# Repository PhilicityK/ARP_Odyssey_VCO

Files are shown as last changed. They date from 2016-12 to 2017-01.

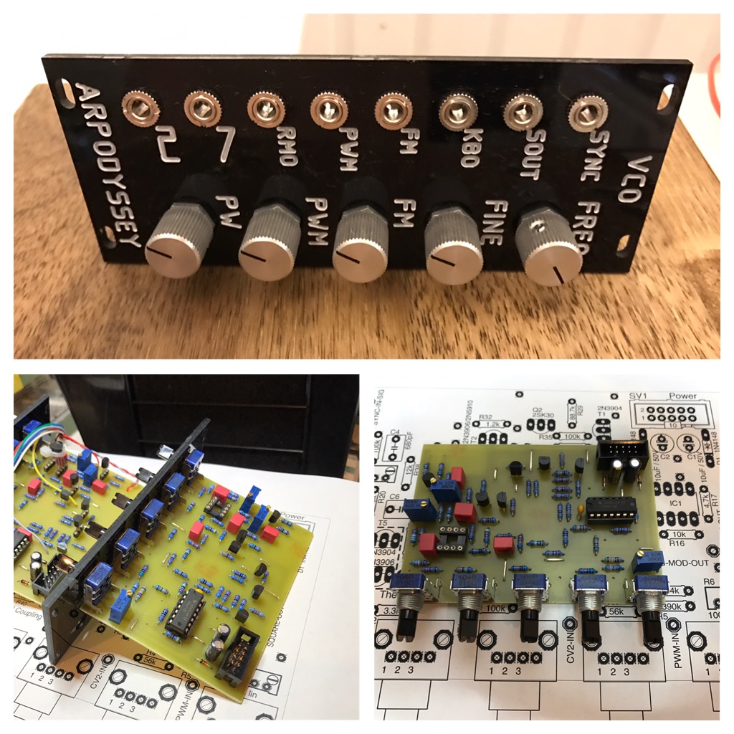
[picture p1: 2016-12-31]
images/IMG_5406.JPG

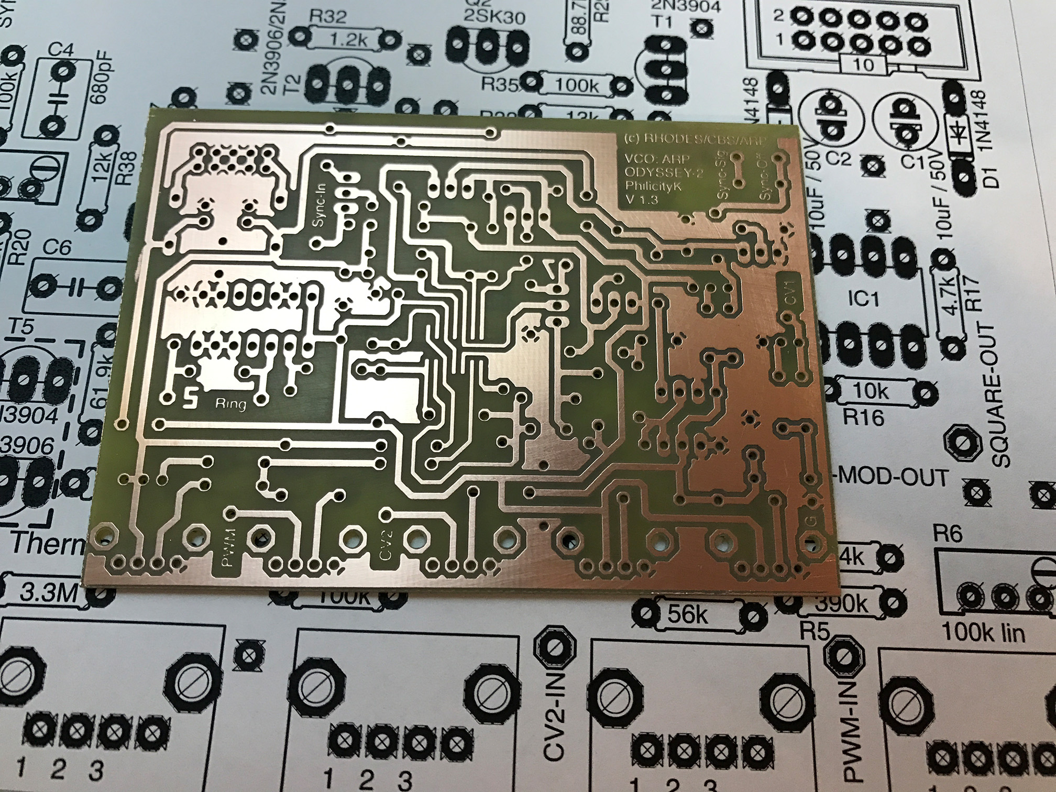
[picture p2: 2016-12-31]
images/finished-pcb.jpg

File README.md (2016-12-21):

ARP_Odyssey_VCO

Modular Version of the ARP ODYSSEY MKII/III VCO

ABOUT THIS PROJECT

Dreaming of my own modular synthesizer for many years, I've decided to finally start a DIY project. First of all I wanted to build a module which allows me to create sounds. I mean what’s the most exited thing about synthesizers? Right! Turning knobs, altering sounds and waveforms! ;) Therefore I have chosen to build the VCO from an ARP ODYSSEY MKII. If you are not familiar with the ODYSSEY just head over to Youtube and have a quick listen to it. It sounds awesome! :)

ABOUT THE CIRCUIT

The great thing about vintage electronics is the availability of official service and repair manuals. I’ve found one for the ARP ODYSSEY online:
http://www.arpodyssey.com/manuals/Arp%20Odyssey%20Service%20Manual.pdf

With the original schematics at my fingertips it was fairly easy to find the VCO section. I’ve used the latest version of EAGLE (7.7.0) to rebuild the circuit. My goal was to keep it simple by using parts which are still available and easily obtainable. I was able to get everything at my distributor of choice (www.reichelt.de). The VCO operates at +/-15V. It might be possible to use it with +/-12V to create sounds, but at lower voltages the CV-tracking will be most likely inaccurate.
This thread over at electro-music gave me a few ideas on how to design my front panel: 
http://files.electro-music.com/forum/topic-54502.html

BUILDING PROCESS

The PCB is home etched and drilled on my DIY CNC machine. 
Soldering is done with an ERSA soldering iron.
The front panel is created from black acrylic which is CNC machined as well.
I’ve used a white pen with a fine tip to fill in the engraved font.

Have a look at the wiki for further informations on building this module.

IMPORTANT

I have not created the schematics for the ARP Odyssey MKII/III VCO. I have just reworked the layout for all the DIY synth builders out there.

Copyright exists (Rhodes/CBS/ARP). No infringement is intended. The files are for experimental and educational purposes only. All the credits for the schematics go to the copyright holder.

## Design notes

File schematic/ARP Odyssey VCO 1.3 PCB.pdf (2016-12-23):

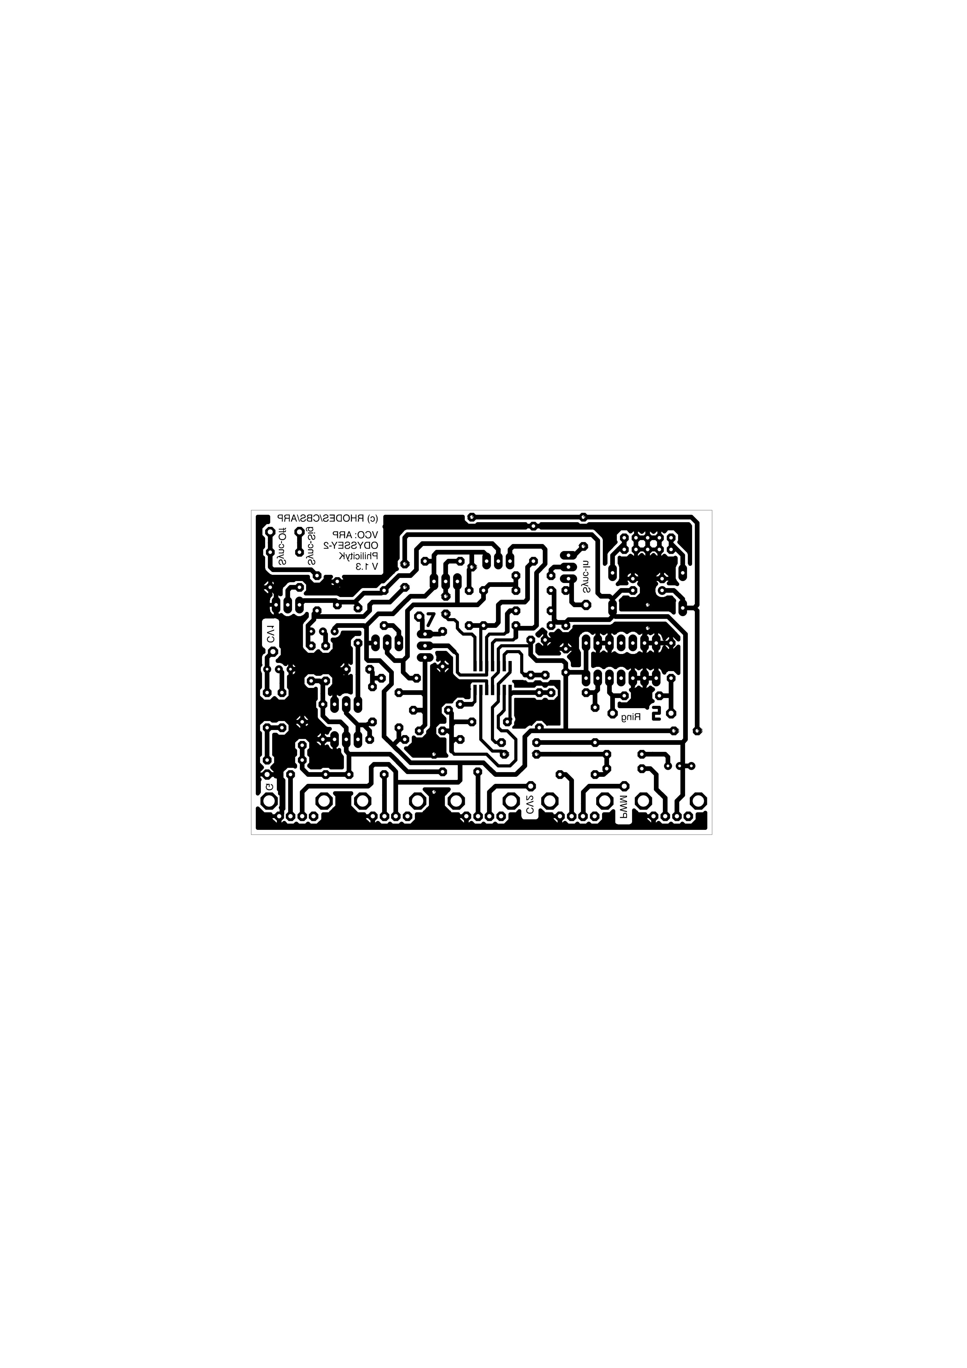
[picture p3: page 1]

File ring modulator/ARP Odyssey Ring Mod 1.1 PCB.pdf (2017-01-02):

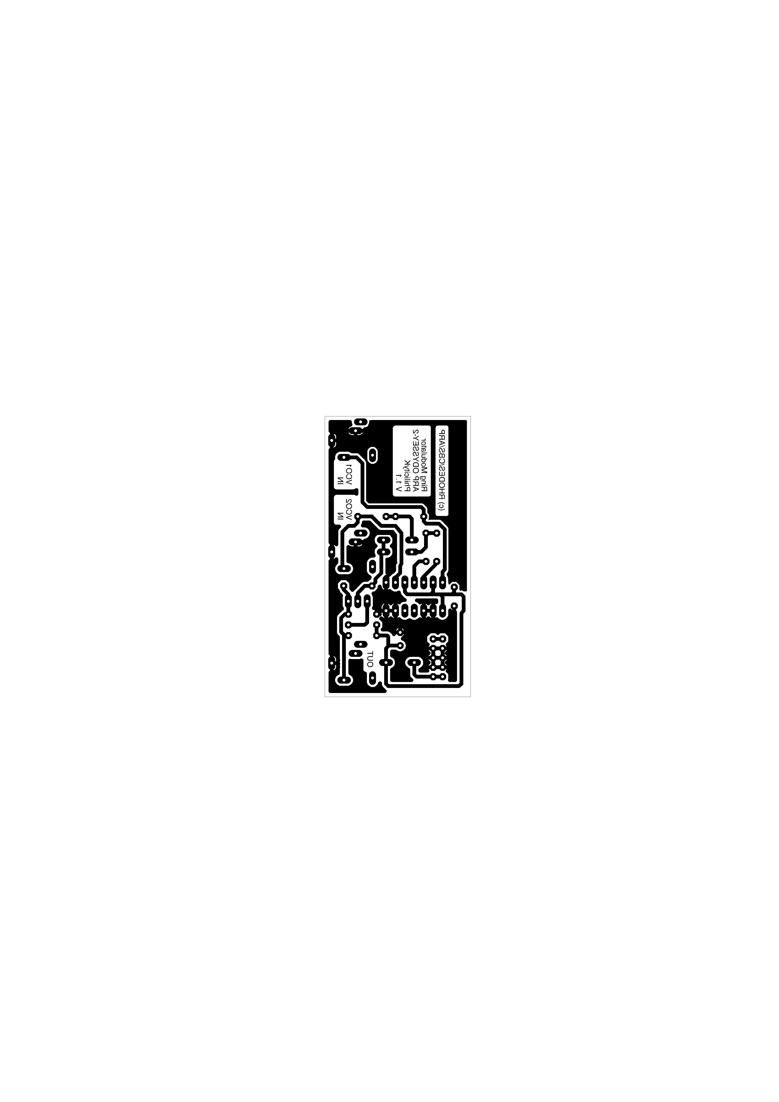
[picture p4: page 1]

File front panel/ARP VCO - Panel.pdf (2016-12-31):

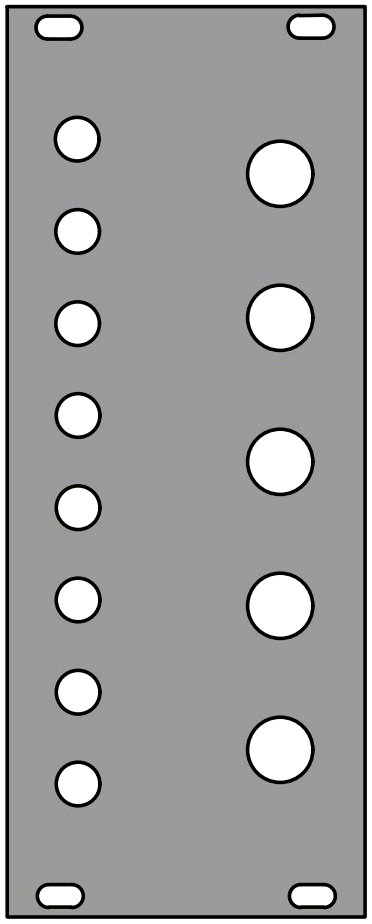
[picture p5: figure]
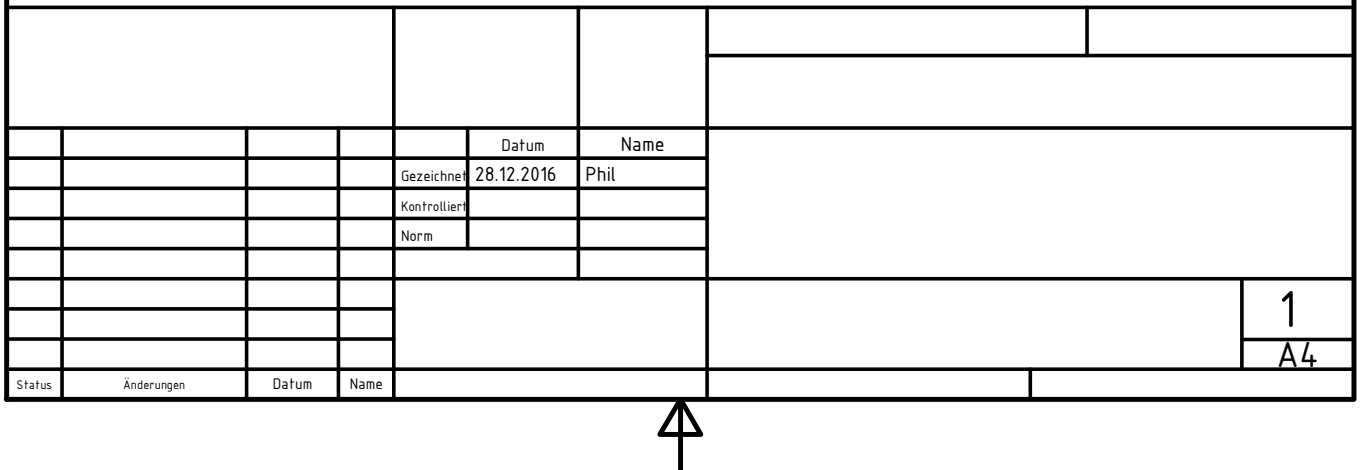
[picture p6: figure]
eic; lie; hil

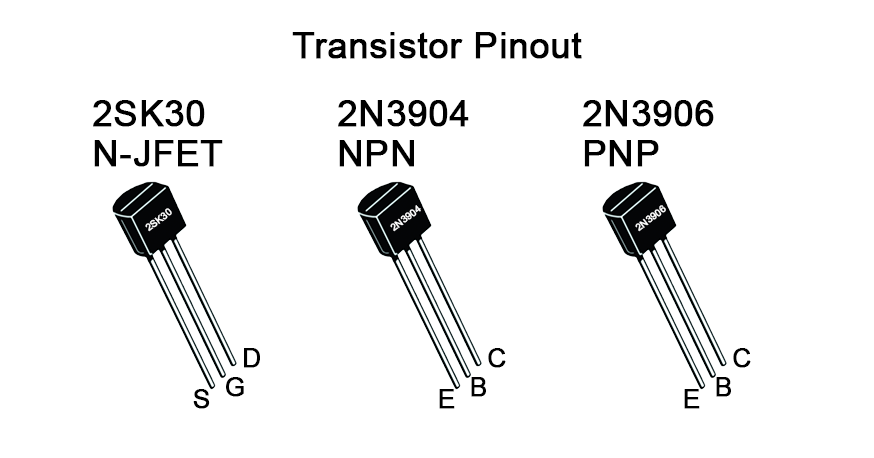
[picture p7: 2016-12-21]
images/Transistor-Pinout.png

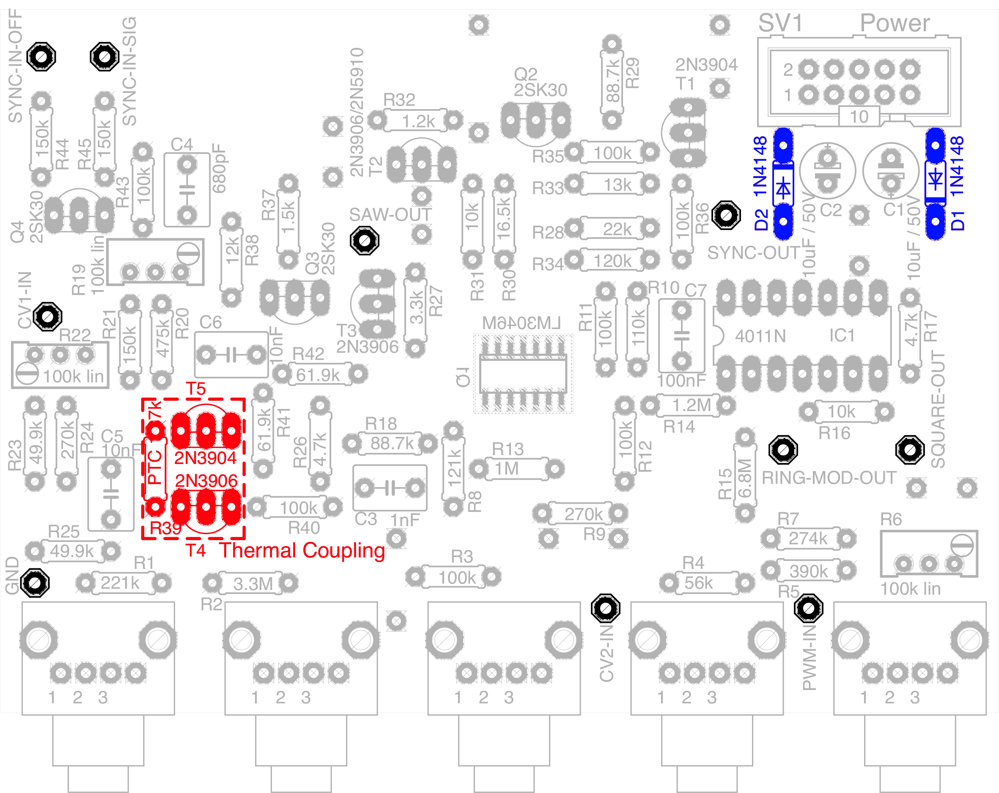
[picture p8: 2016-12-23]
images/ARP Odyssey VCO 1.3 - Information.png

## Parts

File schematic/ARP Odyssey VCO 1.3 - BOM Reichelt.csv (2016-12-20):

Qty | Value | Device | Package | Parts | Description | Reichelt | Total (Euro)
2 | 10uF / 50V | CPOL-EUE2,5-6E | E2,5-6E | C1, C2 | POLARIZED CAPACITOR, European symbol | RAD FC 10/50 | 0,20
1 | 1nF | C-EU050-045X075 | C050-045X075 | C3 | CAPACITOR, European symbol | FKP2-63 1,0N | 0,13
1 | 680pF | C-EU050-045X075 | C050-045X075 | C4 | CAPACITOR, European symbol | FKP2-100 680P | 0,13
2 | 10nF | C-EU050-045X075 | C050-045X075 | C5, C6 | CAPACITOR, European symbol | FKP2-63 10N | 0,15
1 | 100nF | C-EU050-045X075 | C050-045X075 | C7 | CAPACITOR, European symbol | MKS2-63 100N | 0,13
5 | 100k lin | RK11K112 | RK11K112 | CV2-LEVEL, FREQ-COARSE, FREQ-FINE, PULSE-WIDTH, PWM-LEVEL | ALPS-Potentiometer | RK11K112-LIN100K | 6,75
2 | 1N4148 | 1N4148DO35-7 | DO35-7 | D1, D2 | DIODE | 1N 4148 | 0,08
1 | 4011N | 4011N | DIL14 | IC1 | Quad 2-input NAND | MOS 4011 | 0,24
1 | LM3046M/NOPB | LM3046M/NOPB | SO14 | Q1 | Texas Instruments LM3046 | LM 3046 M | 0,80
3 | 2SK30 | 2SK30 | TO92 | Q2, Q3, Q4 | Transistor N-FET | 2SK 30 | 2,58
1 | 221k | R-EU_0207/7 | 0207/7 | R1 | RESISTOR, European symbol | METALL 221K | 0,08
1 | 110k | R-EU_0207/7 | 0207/7 | R10 | RESISTOR, European symbol | METALL 110K | 0,08
1 | 1M | R-EU_0207/7 | 0207/7 | R13 | RESISTOR, European symbol | METALL 1,00M | 0,08
1 | 1.2M | R-EU_0207/7 | 0207/7 | R14 | RESISTOR, European symbol | METALL 1,20M | 0,08
1 | 6.8M | R-EU_0207/7 | 0207/7 | R15 | RESISTOR, European symbol | METALL 6,80M | 0,08
2 | 10k | R-EU_0207/7 | 0207/7 | R16, R31 | RESISTOR, European symbol | METALL 10,0K | 0,16
2 | 4.7k | R-EU_0207/7 | 0207/7 | R17, R26 | RESISTOR, European symbol | METALL 4,70K | 0,16
2 | 88.7k | R-EU_0207/7 | 0207/7 | R18, R29 | RESISTOR, European symbol | METALL 88,7K | 0,16
1 | 3.3M | R-EU_0207/7 | 0207/7 | R2 | RESISTOR, European symbol | METALL 3,30M | 0,08
1 | 475k | R-EU_0207/7 | 0207/7 | R20 | RESISTOR, European symbol | METALL 475K | 0,08
3 | 150k | R-EU_0207/7 | 0207/7 | R21, R44, R45 | RESISTOR, European symbol | METALL 150K | 0,25
2 | 49.9k | R-EU_0207/7 | 0207/7 | R23, R25 | RESISTOR, European symbol | METALL 49,9K | 0,16
1 | 3.3k | R-EU_0207/7 | 0207/7 | R27 | RESISTOR, European symbol | METALL 3,30K | 0,08
1 | 22k | R-EU_0207/7 | 0207/7 | R28 | RESISTOR, European symbol | METALL 22,0K | 0,08
7 (10) | 100k | R-EU_0207/7 | 0207/7 | R3, R11, R12, R35, R36, R40, R43 | RESISTOR, European symbol (10pcs are cheaper than 7) | METALL 100K | 0,49
1 | 16.5k | R-EU_0207/7 | 0207/7 | R30 | RESISTOR, European symbol | METALL 16,5K | 0,08
1 | 1.2k | R-EU_0207/7 | 0207/7 | R32 | RESISTOR, European symbol | METALL 1,20K | 0,08
1 | 13k | R-EU_0207/7 | 0207/7 | R33 | RESISTOR, European symbol | METALL 13,0K | 0,08
1 | 120k | R-EU_0207/7 | 0207/7 | R34 | RESISTOR, European symbol | METALL 120K | 0,08
1 | 1.5k | R-EU_0207/7 | 0207/7 | R37 | RESISTOR, European symbol | METALL 1,50K | 0,08
1 | 12k | R-EU_0207/7 | 0207/7 | R38 | RESISTOR, European symbol | METALL 12,0K | 0,08
1 | PTC 1.87k | R-EU_0207/7 | 0207/7 | R39 | PTC (TEMPCO 1.87k 3400ppm would be better but isn't avaliable from Reichelt) | KTY 81-210 | 0,63
1 | 56k | R-EU_0207/7 | 0207/7 | R4 | RESISTOR, European symbol | METALL 56,0K | 0,08
2 | 61.9k | R-EU_0207/7 | 0207/7 | R41, R42 | RESISTOR, European symbol | METALL 62,0K | 0,16
1 | 390k | R-EU_0207/7 | 0207/7 | R5 | RESISTOR, European symbol | METALL 390K | 0,08
3 | 100k lin | R-TRIMM64W | RTRIM64W | R6, R19, R22 | Trimm resistor | 64W-100K | 0,96
1 | 274k | R-EU_0207/7 | 0207/7 | R7 | RESISTOR, European symbol | METALL 274K | 0,08
1 | 121k | R-EU_0207/7 | 0207/7 | R8 | RESISTOR, European symbol | METALL 121K | 0,08
2 | 270k | R-EU_0207/7 | 0207/7 | R9, R24 | RESISTOR, European symbol | METALL 270K | 0,08
1 | Power | ML10 | ML10 | SV1 | HARTING | WSL 10G | 0,09
2 | 2N3904 | 2N3904-NPN-TO92-EBC | TO92-EBC | T1, T5 | NPN Transistror | 2N 3904 | 0,16
1 | 2N3906/2N5910 | 2N3906-PNP-TO92-EBC | TO92-EBC | T2 | PNP Transistror | 2N 3906 | 0,04
2 | 2N3906 | 2N3906-PNP-TO92-EBC | TO92-EBC | T3, T4 | PNP Transistror | 2N 3906 | 0,08
1 |  |  |  |  | Single sided PCB | BEL 75X100-1 | 0,99
8 |  |  |  |  | 3,5mm switched mono jacks | LUM 1502-03 | 6,88
 |  |  |  |  |  |  | 24,22

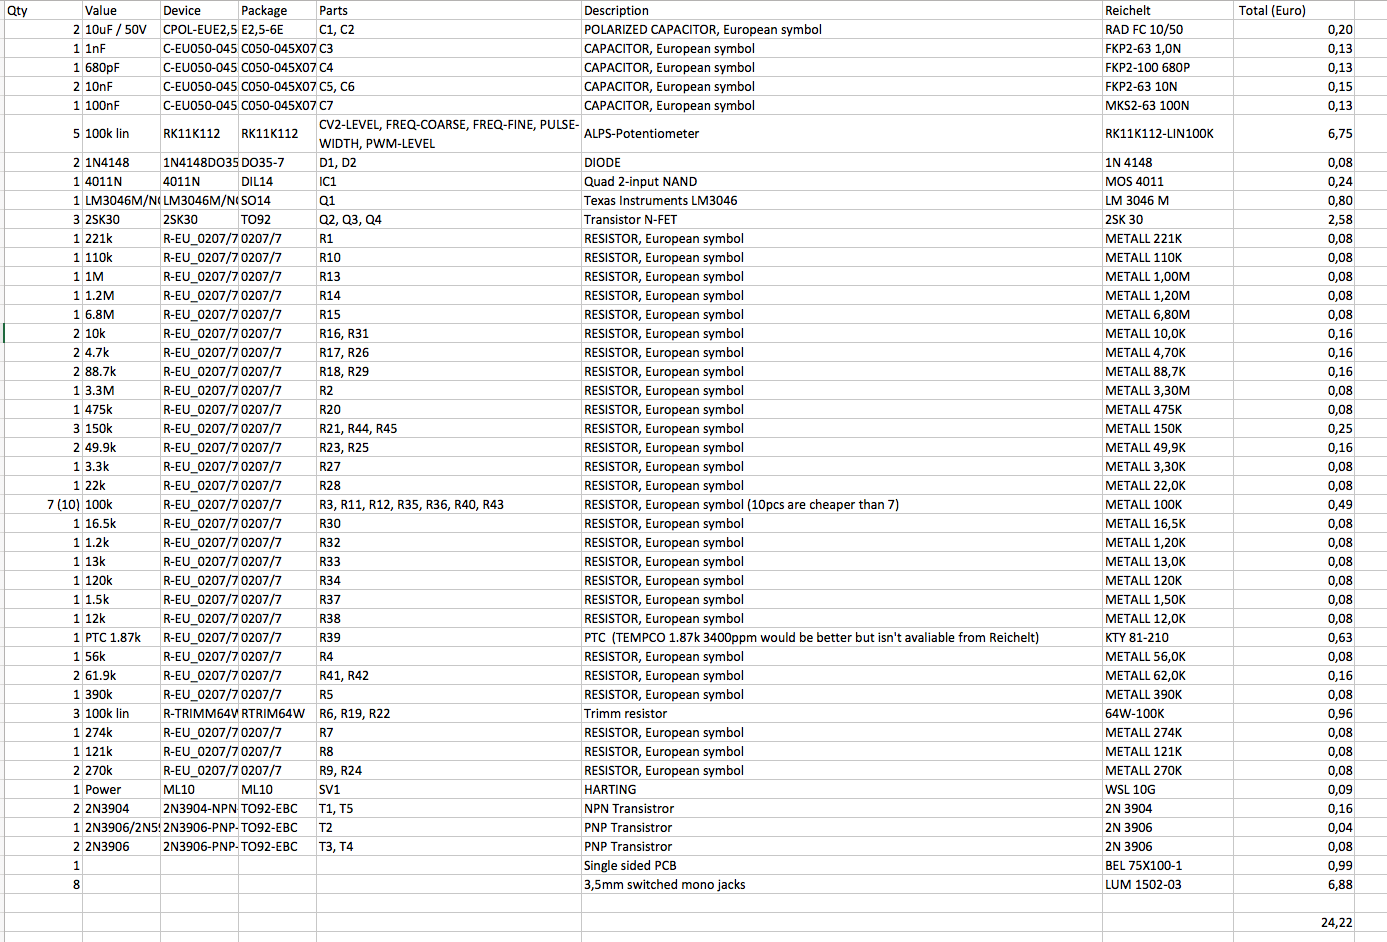
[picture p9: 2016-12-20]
schematic/BOM V1.3.png

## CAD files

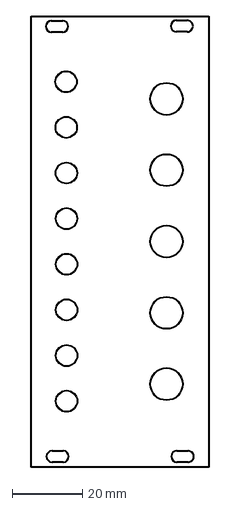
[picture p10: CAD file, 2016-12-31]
front panel/ARP VCO - Panel.dxf
50.5 x 128.5 mm

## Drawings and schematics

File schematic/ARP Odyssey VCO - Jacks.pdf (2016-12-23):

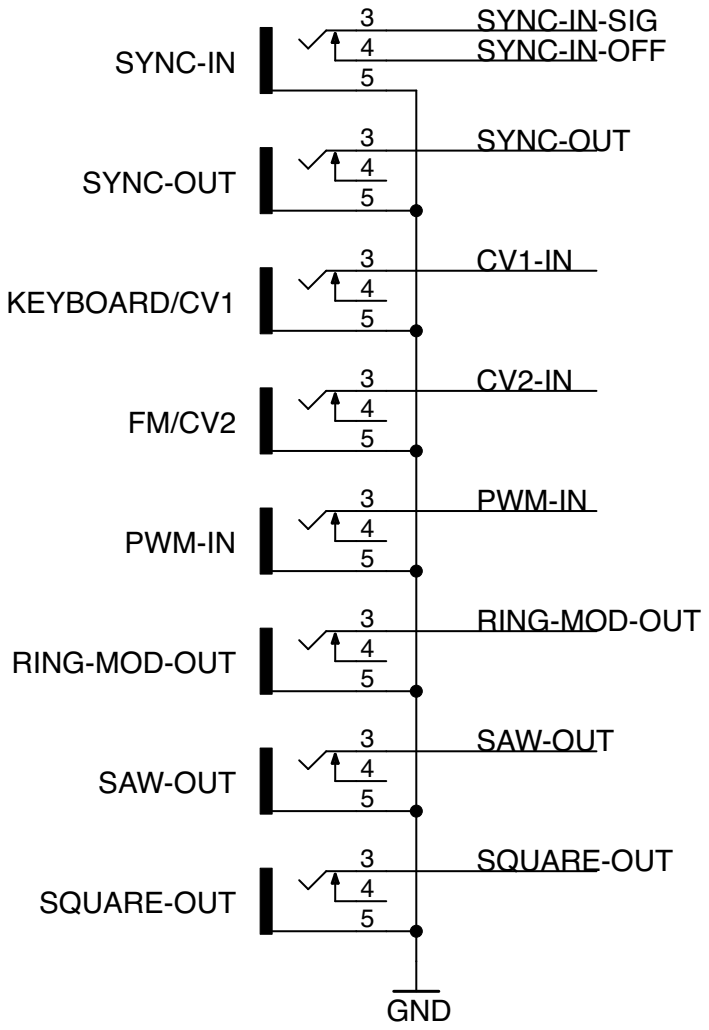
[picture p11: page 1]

This schematic shows how to connect the output jacks to the board

ARP Odyssey VCO - Jacks

Document Number: | REV:

Date: 21.12.16 15:11 | Sheet: 1/1

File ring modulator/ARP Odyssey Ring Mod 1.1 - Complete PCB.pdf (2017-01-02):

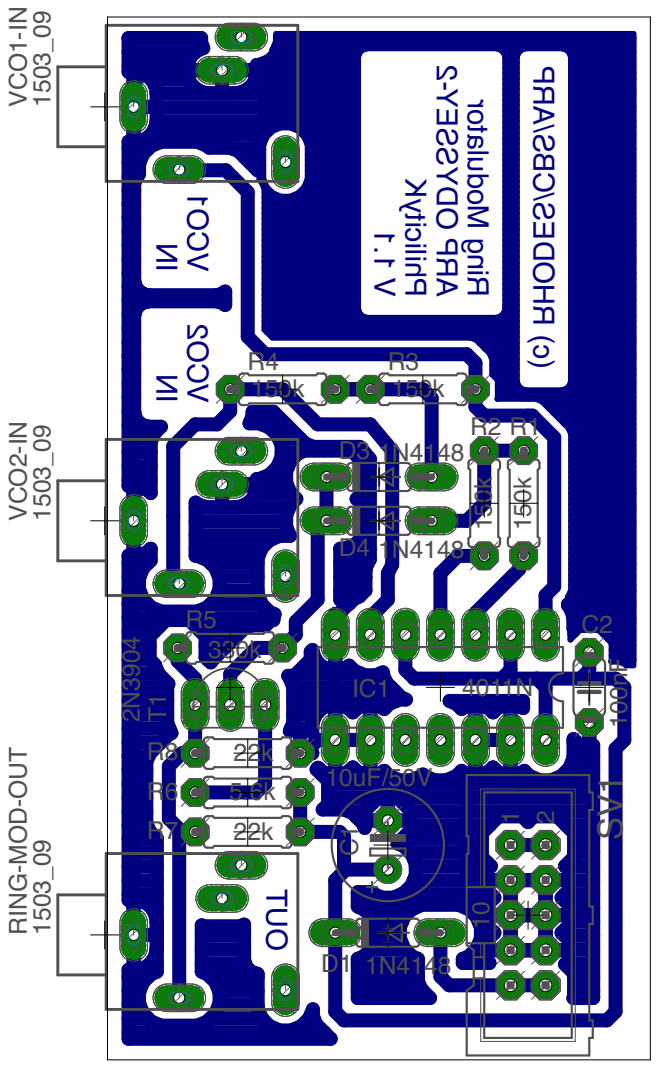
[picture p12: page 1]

Ring Modulator ARP ODYSSEY-2 PhilicityK V 1.1 (c) RHODES/CBS/ARP VCO1 IN VCO2 IN OUT10 12 C1 D1IC1 SV1 R2 R1 R4 R3 D3 D4 T1 R5 R6 R7 R8 C2 VCO1-IN VCO2-IN RING-MOD-OUT 10uF/50V 1N4148 4011N150k 150k 150k 150k 1N4148 1N4148 2N3904330k 5.6k 22k 22k 100nF 1503_09 1503_09 1503_09

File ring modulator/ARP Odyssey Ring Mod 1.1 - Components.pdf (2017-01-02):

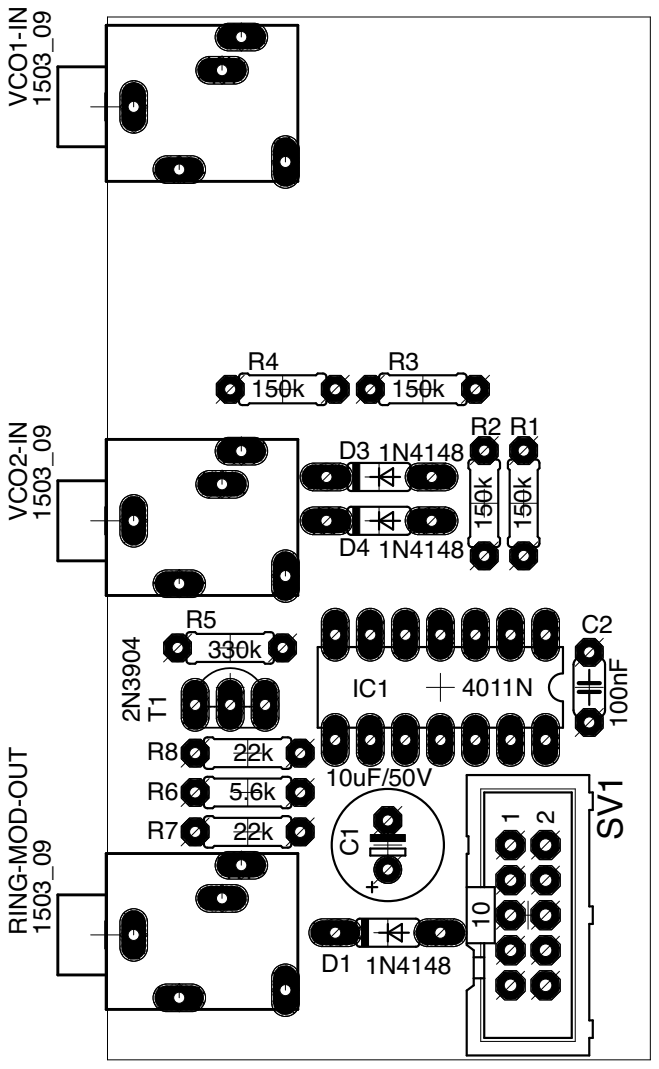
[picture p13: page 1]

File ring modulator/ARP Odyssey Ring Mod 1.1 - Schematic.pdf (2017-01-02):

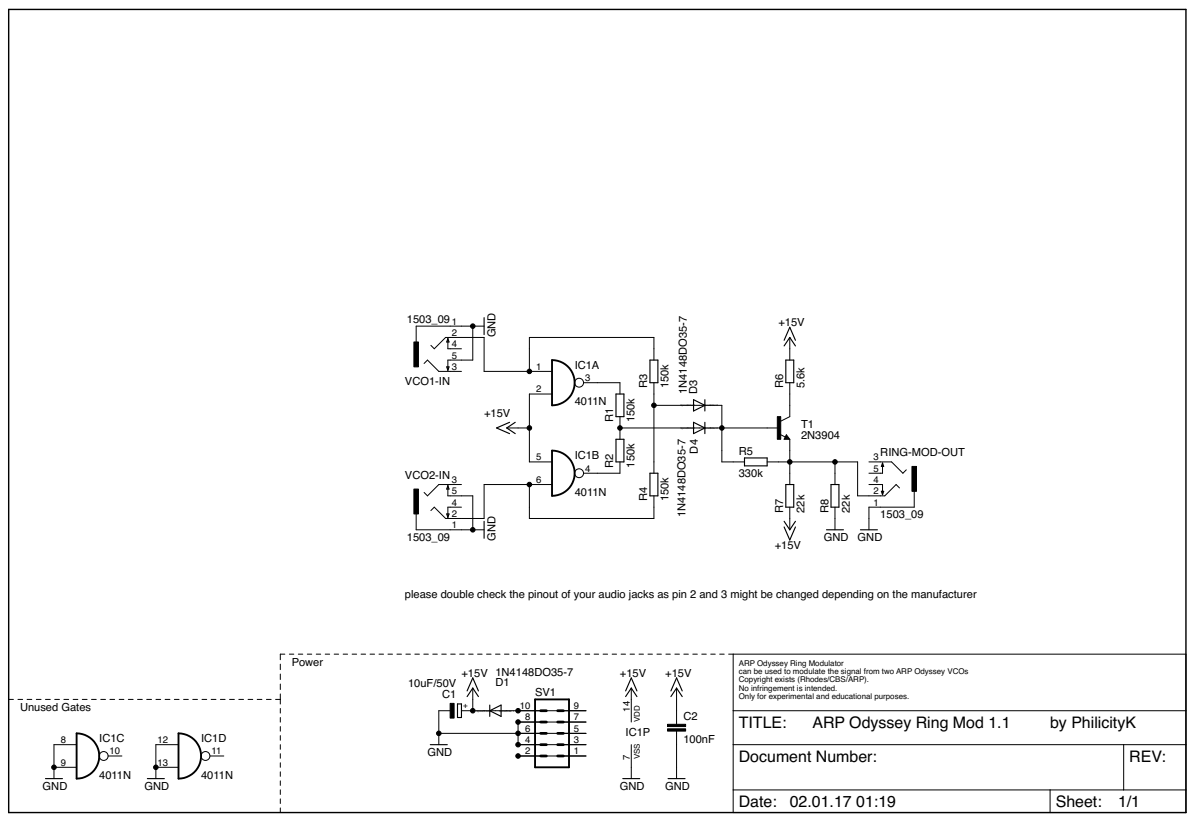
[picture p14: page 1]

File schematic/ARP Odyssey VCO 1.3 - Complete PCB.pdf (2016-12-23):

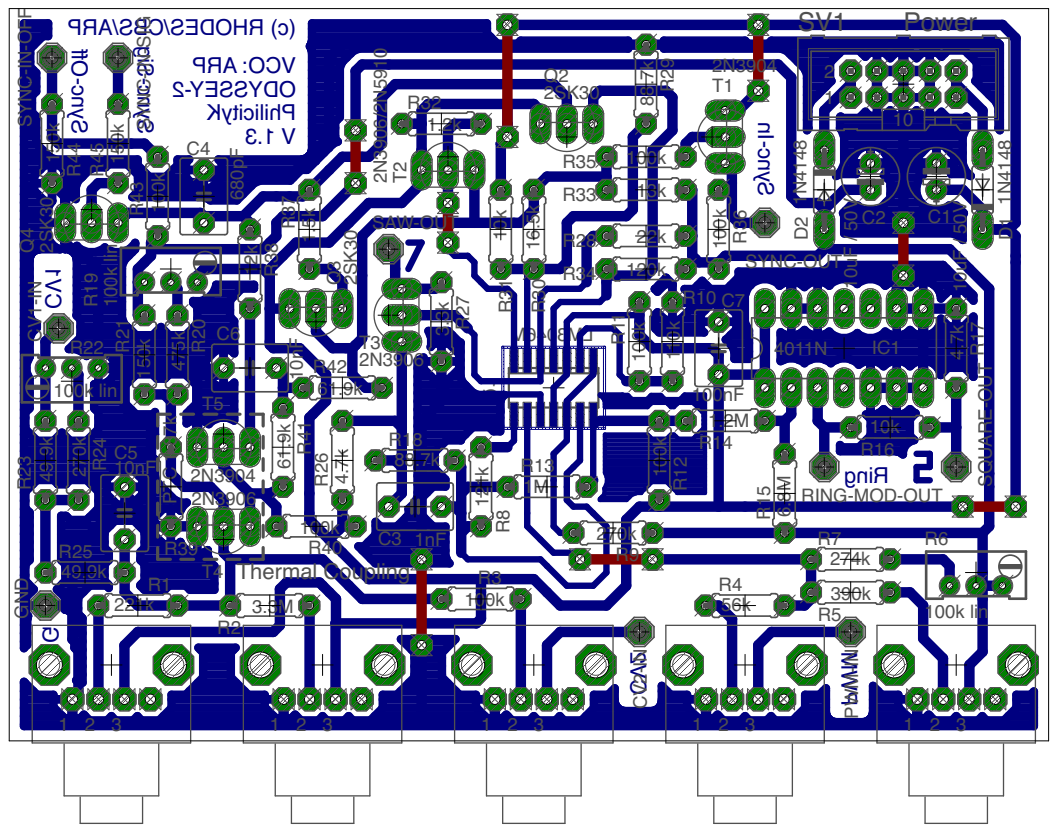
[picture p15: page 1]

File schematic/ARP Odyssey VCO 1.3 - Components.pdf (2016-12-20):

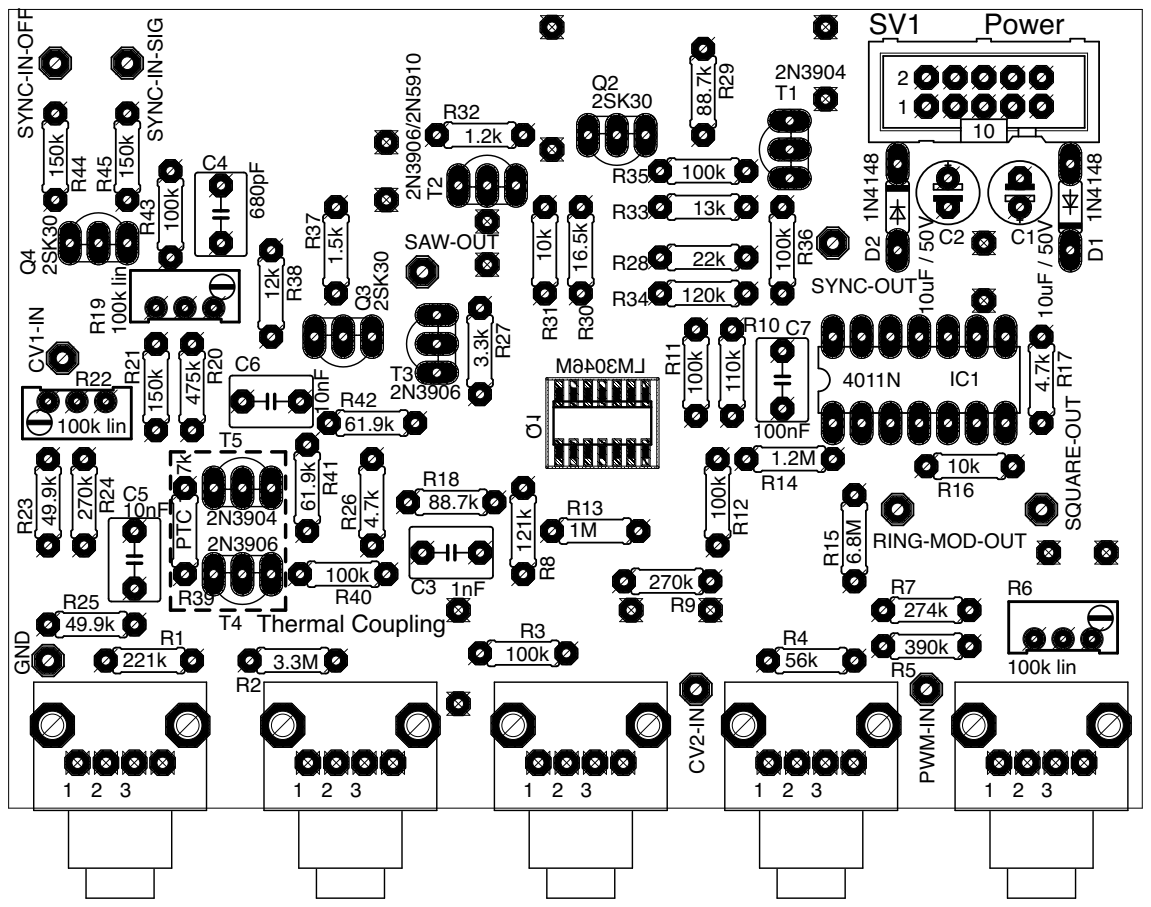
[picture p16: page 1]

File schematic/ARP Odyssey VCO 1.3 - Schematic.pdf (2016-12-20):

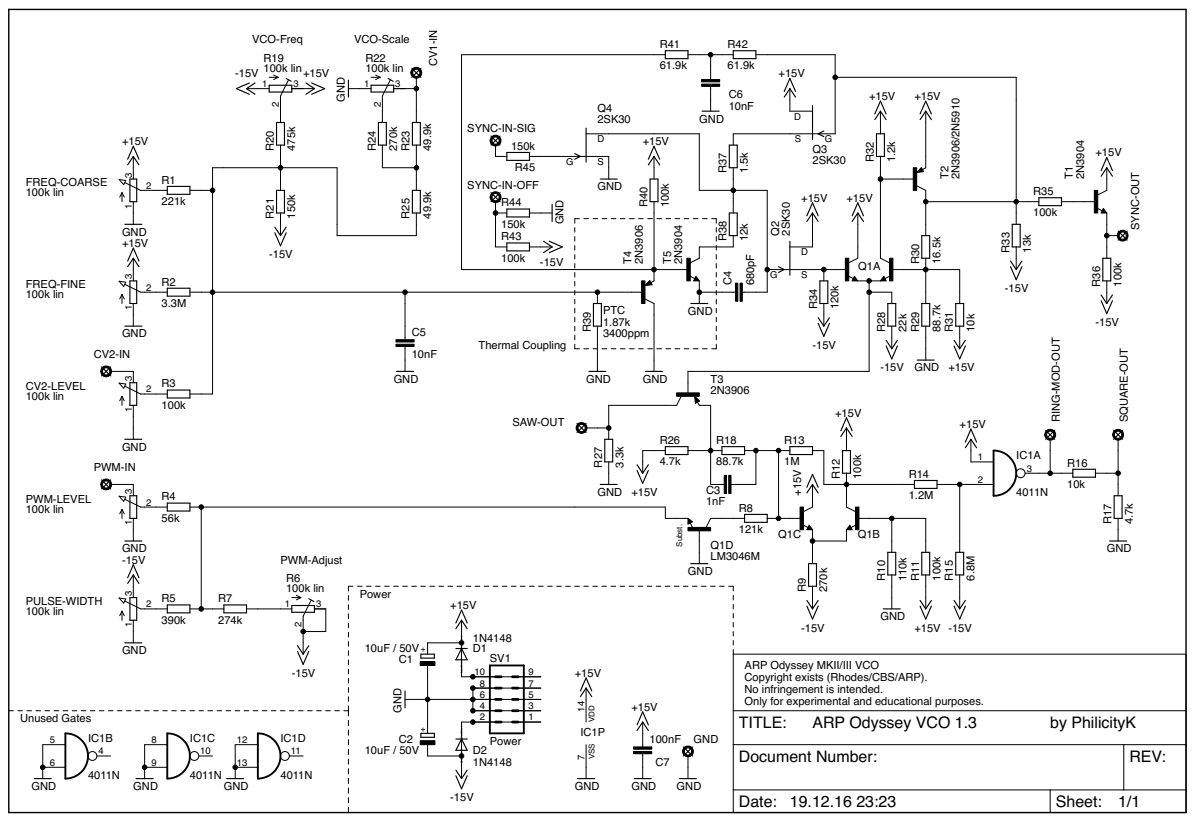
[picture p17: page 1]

OD-OUT SQUARE-OUT R16 R17

SpiceOrder 1 SpiceOrder 2

ARP Odyssey MKII/III VCO

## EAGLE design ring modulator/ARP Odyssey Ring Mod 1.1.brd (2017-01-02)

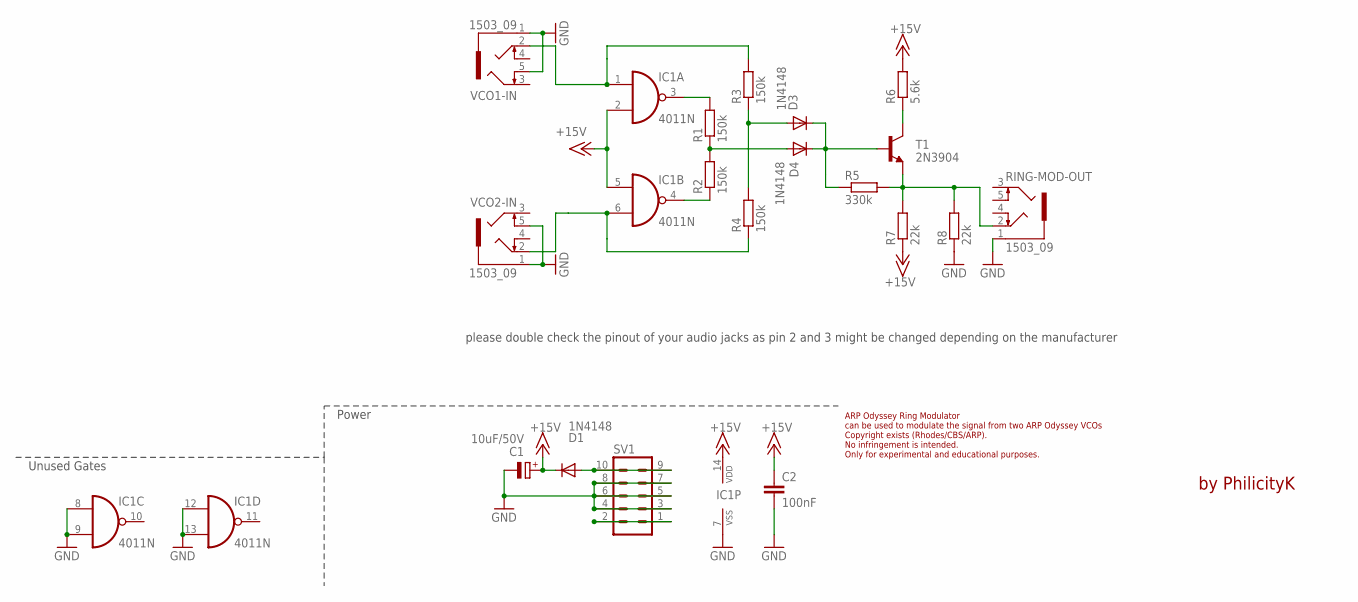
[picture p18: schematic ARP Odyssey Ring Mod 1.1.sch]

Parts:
C1: 10uF/50V; E3,5-8
C2: 100nF; C050-024X044
D1, D3, D4: 1N4148; DO35-7
IC1: 4011N; DIL14
R1, R2, R3, R4: 150k; 0207/7
R5: 330k; 0207/7
R6: 5.6k; 0207/7
R7, R8: 22k; 0207/7
RING-MOD-OUT: 1503_09
SV1: ML10
T1: 2N3904; TO92-EBC
VCO1-IN, VCO2-IN: 1503_09

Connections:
+15V: C1.+, C2.1, D1.C, IC1.2 (I1), IC1.5 (I0), IC1.14 (VDD), R6.2, R7.1
GND: C1.-, C2.2, IC1.7 (VSS), IC1.8 (I0), IC1.9 (I1), IC1.12 (I0), IC1.13 (I1), R8.1, RING-MOD-OUT.1, SV1.3, SV1.4, SV1.5, SV1.6, SV1.7, SV1.8, VCO1-IN.1, VCO1-IN.5, VCO2-IN.1, VCO2-IN.5
unnamed: D1.A, SV1.9, SV1.10
unnamed: IC1.3 (O), R1.2
unnamed: IC1.4 (O), R2.1
unnamed: D4.A, R1.1, R2.2
unnamed: SV1.1, SV1.2
unnamed: R5.2, R7.2, R8.2, RING-MOD-OUT.2, T1.E
unnamed: IC1.6 (I1), R4.1, VCO2-IN.2
unnamed: IC1.1 (I0), R3.2, VCO1-IN.2
unnamed: D3.A, R3.1, R4.2
unnamed: D3.C, D4.C, R5.1, T1.B
unnamed: R6.1, T1.C

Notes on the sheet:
ARP Odyssey Ring Modulator can be used to modulate the signal from two ARP Odyssey VCOs Copyright exists (Rhodes/CBS/ARP). No infringement is intended. Only for experimental and educational purposes.
Unused Gates
Power
by PhilicityK
please double check the pinout of your audio jacks as pin 2 and 3 might be changed depending on the manufacturer

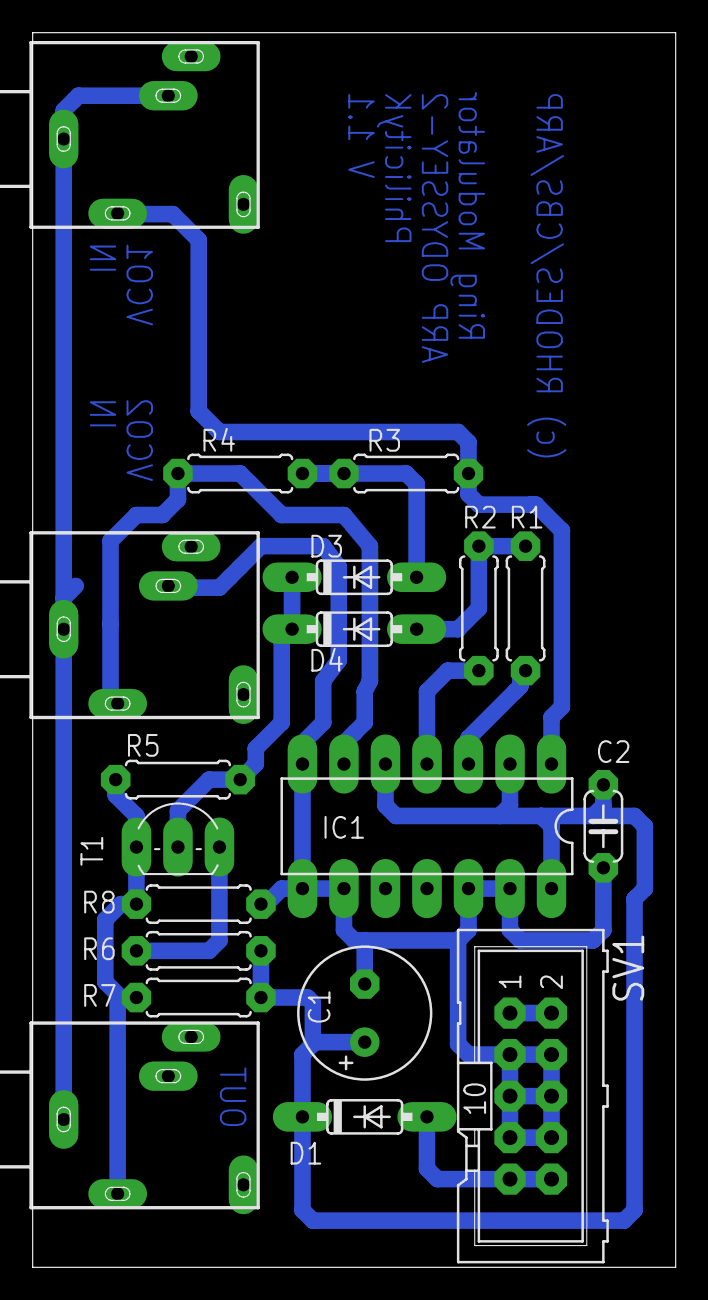
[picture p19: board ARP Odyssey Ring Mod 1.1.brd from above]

Board: 2 copper layers, 39.4 x 75.6 mm, 19 parts (0 on the bottom side), 13 nets.

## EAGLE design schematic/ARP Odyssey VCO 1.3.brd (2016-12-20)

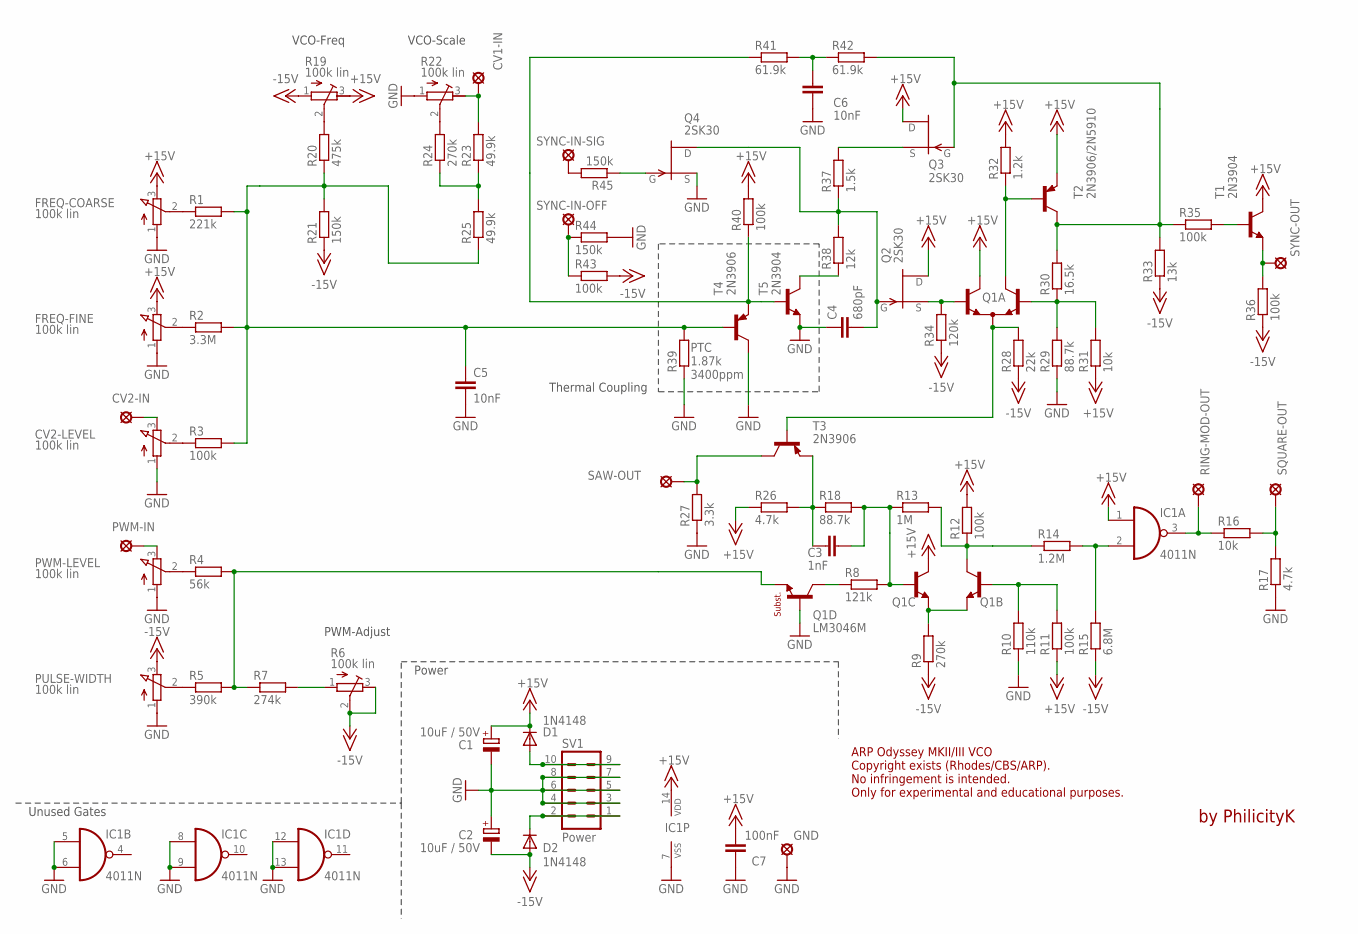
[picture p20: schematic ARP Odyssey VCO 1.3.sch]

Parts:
C1, C2: 10uF / 50V; E2,5-6E
C3: 1nF; C050-045X075
C4: 680pF; C050-045X075
C5, C6: 10nF; C050-045X075
C7: 100nF; C050-045X075
CV1-IN, CV2-IN: SE11
CV2-LEVEL: 100k lin; RK11K112
D1, D2: 1N4148; DO35-7
FREQ-COARSE: 100k lin; RK11K112
FREQ-FINE: 100k lin; RK11K112
GND: SE11
IC1: 4011N; DIL14
PULSE-WIDTH: 100k lin; RK11K112
PWM-IN: SE11
PWM-LEVEL: 100k lin; RK11K112
Q1: LM3046M; SO14
Q2, Q3, Q4: 2SK30; TO92
R1: 221k; 0207/7
R2: 3.3M; 0207/7
R3, R11, R12, R35, R36, R40, R43: 100k; 0207/7
R4: 56k; 0207/7
R5: 390k; 0207/7
R6, R19, R22: 100k lin; RTRIM64W
R7: 274k; 0207/7
R8: 121k; 0207/7
R9, R24: 270k; 0207/7
R10: 110k; 0207/7
R13: 1M; 0207/7
R14: 1.2M; 0207/7
R15: 6.8M; 0207/7
R16, R31: 10k; 0207/7
R17, R26: 4.7k; 0207/7
R18, R29: 88.7k; 0207/7
R20: 475k; 0207/7
R21, R44, R45: 150k; 0207/7
R23, R25: 49.9k; 0207/7
R27: 3.3k; 0207/7
R28: 22k; 0207/7
R30: 16.5k; 0207/7
R32: 1.2k; 0207/7
R33: 13k; 0207/7
R34: 120k; 0207/7
R37: 1.5k; 0207/7
R38: 12k; 0207/7
R39: PTC 1.87k; 0207/7
R41, R42: 61.9k; 0207/7
RING-MOD-OUT: SE11
SAW-OUT: SE11
SQUARE-OUT: SE11
SV1: Power; ML10
SYNC-IN-OFF: SE11
SYNC-IN-SIG: SE11
SYNC-OUT: SE11
T1, T5: 2N3904; TO92-EBC
T2: 2N3906/2N5910; TO92-EBC
T3, T4: 2N3906; TO92-EBC

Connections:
+15V: C1.+, C7.2, D1.C, FREQ-COARSE.3 (E), FREQ-FINE.3 (E), IC1.1 (I0), IC1.14 (VDD), Q1.5 (C2), Q1.11 (C), Q2.3 (D), Q3.3 (D), R11.2, R12.2, R19.3 (E), R26.1, R31.2, R32.2, R40.1, T1.C, T2.E
-15V: C2.-, D2.A, PULSE-WIDTH.3 (E), R6.2 (S), R6.3 (E), R9.1, R15.1, R19.1 (A), R21.2, R28.1, R33.1, R34.1, R36.2, R43.2
GND: C1.-, C2.+, C4.1, C5.2, C6.2, C7.1, CV2-LEVEL.1 (A), FREQ-COARSE.1 (A), FREQ-FINE.1 (A), GND.MP, IC1.5 (I0), IC1.6 (I1), IC1.7 (VSS), IC1.8 (I0), IC1.9 (I1), IC1.12 (I0), IC1.13 (I1), PULSE-WIDTH.1 (A), PWM-LEVEL.1 (A), Q1.12 (B), Q4.1 (S), R10.1, R17.1, R22.1 (A), R27.2, R29.1, R39.1, R44.2, SV1.3, SV1.4, SV1.5, SV1.6, SV1.7, SV1.8, T4.C, T5.E
unnamed: D2.C, SV1.1, SV1.2
unnamed: FREQ-COARSE.2 (S), R1.1
unnamed: FREQ-FINE.2 (S), R2.1
unnamed: C5.1, R1.2, R2.2, R3.2, R20.2, R21.1, R25.2, R39.2, T4.B
unnamed: D1.A, SV1.9, SV1.10
unnamed: CV2-LEVEL.2 (S), R3.1
unnamed: CV2-IN.MP, CV2-LEVEL.3 (E)
unnamed: PWM-IN.MP, PWM-LEVEL.3 (E)
unnamed: PWM-LEVEL.2 (S), R4.1
unnamed: PULSE-WIDTH.2 (S), R5.1
unnamed: Q1.13 (E), R4.2, R5.2, R7.1
unnamed: R6.1 (A), R7.2
unnamed: Q1.14 (C), R8.1
unnamed: C3.2, Q1.9 (B), R8.2, R13.1, R18.2
unnamed: Q1.7 (E), Q1.10 (E), R9.2
unnamed: Q1.6 (B), R10.2, R11.1
unnamed: Q1.8 (C), R12.1, R13.2, R14.1
unnamed: IC1.2 (I1), R14.2, R15.2
unnamed: IC1.3 (O), R16.1, RING-MOD-OUT.MP
unnamed: R16.2, R17.2, SQUARE-OUT.MP
unnamed: C3.1, R18.1, R26.2, T3.E
unnamed: R19.2 (S), R20.1
unnamed: R22.2 (S), R24.1
unnamed: R23.2, R24.2, R25.1
unnamed: CV1-IN.MP, R22.3 (E), R23.1
unnamed: Q1.3 (E), R28.2, T3.B
unnamed: R27.1, SAW-OUT.MP, T3.C
unnamed: Q1.2 (B1), R29.2, R30.1, R31.1
unnamed: Q3.2 (G), R30.2, R33.2, R35.2, R42.1, T2.C
unnamed: Q1.1 (C1), R32.1, T2.B
unnamed: Q1.4 (B2), Q2.1 (S), R34.2
unnamed: R36.1, SYNC-OUT.MP, T1.E
unnamed: R35.1, T1.B
unnamed: Q3.1 (S), R37.1
unnamed: C6.1, R41.1, R42.2
unnamed: R38.2, T5.C
unnamed: R40.2, R41.2, T4.E, T5.B
unnamed: R43.1, R44.1, SYNC-IN-OFF.MP
unnamed: Q4.2 (G), R45.1
unnamed: R45.2, SYNC-IN-SIG.MP
unnamed: C4.2, Q2.2 (G), Q4.3 (D), R37.2, R38.1

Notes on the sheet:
PWM-Adjust
VCO-Scale
VCO-Freq
Thermal Coupling
Unused Gates
Power
PTC 1.87k 3400ppm
ARP Odyssey MKII/III VCO Copyright exists (Rhodes/CBS/ARP). No infringement is intended. Only for experimental and educational purposes.
by PhilicityK

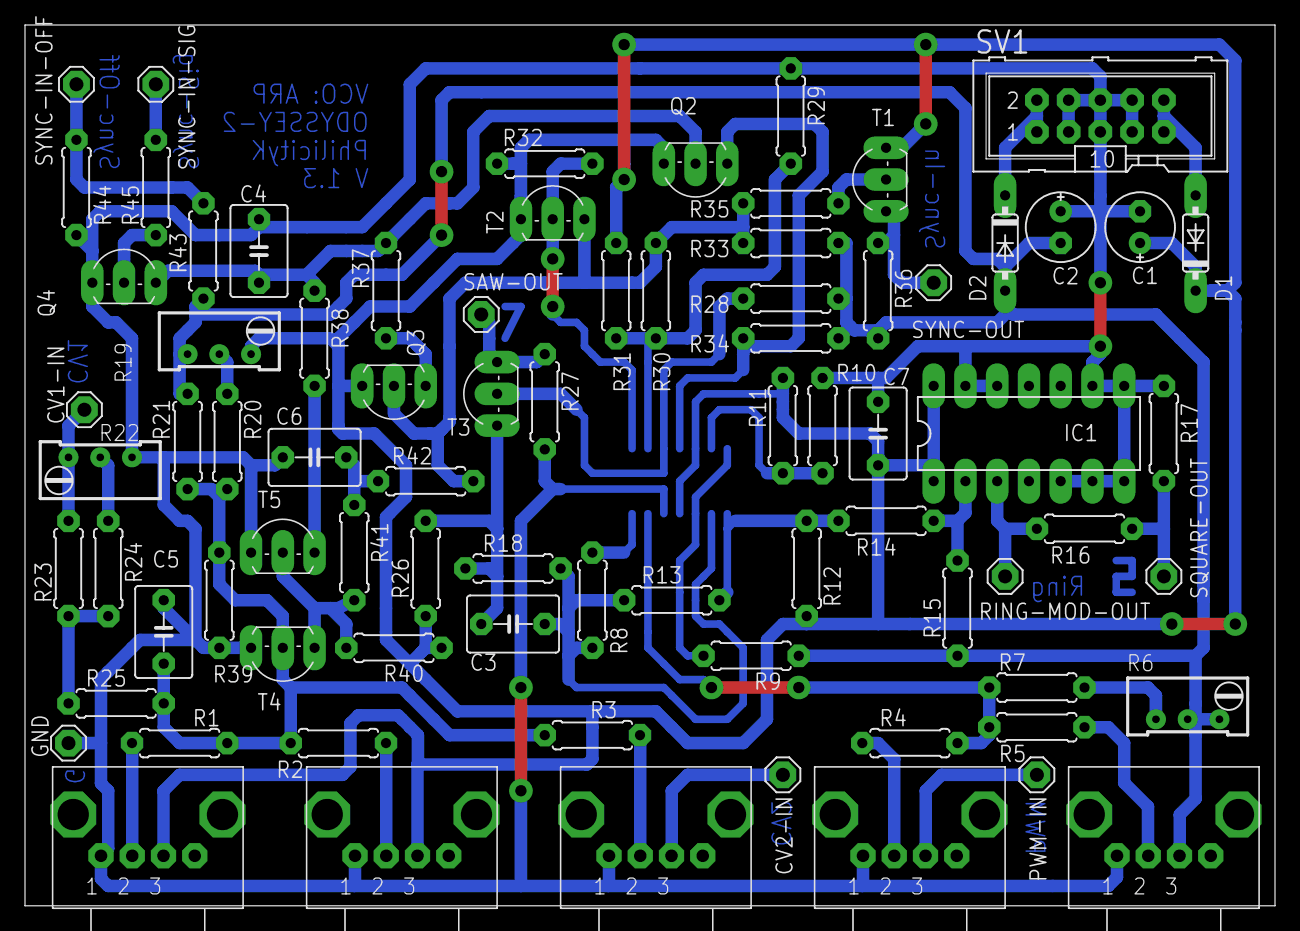
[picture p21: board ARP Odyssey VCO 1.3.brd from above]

Board: 2 copper layers, 100.0 x 70.5 mm, 80 parts (1 on the bottom side), 44 nets.

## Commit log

2016-12-20 ARP Odyssey VCO 1.3 - Schematic
2016-12-20 EAGLE files, PCB and BOM
    [ARP Odyssey VCO 1.3 - BOM Reichelt.csv, ARP Odyssey VCO 1.3.brd, ARP Odyssey VCO 1.3.sch]
2016-12-20 BOM Screenshot
2016-12-20 added images of the board
2016-12-31 added images and panel design
    [ARP VCO - Panel.dxf]
2017-01-02 added the ring modulator
    [ARP Odyssey Ring Mod 1.1.brd, ARP Odyssey Ring Mod 1.1.sch]
